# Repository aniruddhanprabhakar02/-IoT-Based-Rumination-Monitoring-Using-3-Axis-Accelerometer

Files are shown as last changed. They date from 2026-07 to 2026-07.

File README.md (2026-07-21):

# IoT-Based Cattle Rumination Monitoring and Health Analysis System










<p align="center">
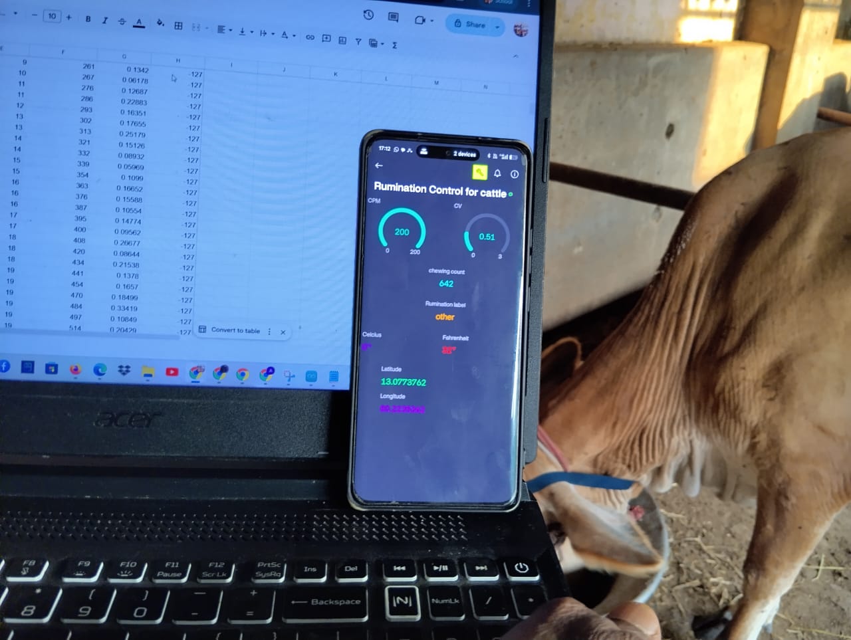
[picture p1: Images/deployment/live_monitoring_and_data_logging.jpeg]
IoT-Based Cattle Rumination Monitoring System
  
</p>

## Project Overview

This project presents an IoT-based cattle monitoring system designed to monitor rumination behavior, body temperature, and cattle location in real time.

The system uses an **ESP32-WROOM-32** microcontroller integrated with an **MPU6050 accelerometer**, **DS18B20 temperature sensor**, and **NEO-6M GPS module**. Accelerometer signals are processed using digital signal processing techniques to estimate chewing activity and classify rumination behavior. The processed data is visualized through a **Blynk IoT dashboard** and logged to **Google Sheets** for long-term monitoring and analysis.

### Applications

- Livestock Health Monitoring
- Precision Livestock Farming
- Behavioral Analytics
- Early Disease Detection
- Heat Stress Monitoring

---

# Key Features

- Real-time rumination monitoring
- Jaw movement sensing using MPU6050
- Signal filtering and peak detection
- Chews Per Minute (CPM) estimation
- Coefficient of Variation (CV) analysis
- Rule-based rumination classification
- Temperature monitoring using DS18B20
- GPS-based cattle tracking
- Blynk IoT dashboard integration
- Google Sheets cloud logging
- Custom PCB design using KiCad
- Field-tested on live cattle

---

# System Workflow

<p align="center">
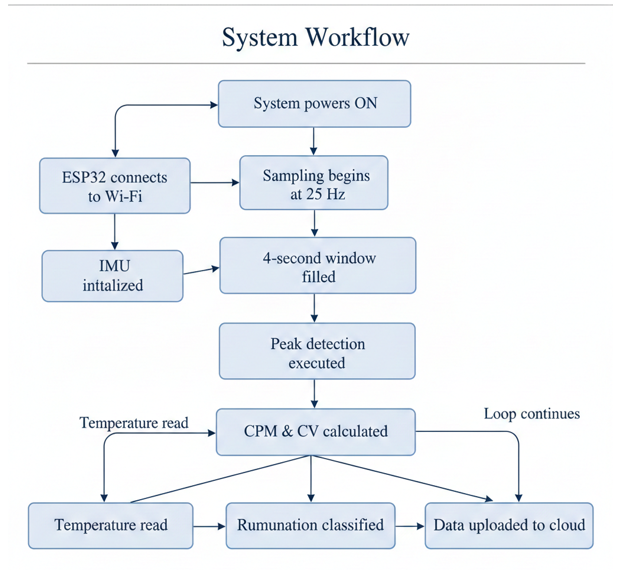
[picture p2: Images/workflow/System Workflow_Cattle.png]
  
</p>

The firmware continuously acquires accelerometer data, applies digital filtering, detects chewing events, computes behavioral metrics (CPM and CV), classifies rumination activity, and uploads the processed information to cloud platforms for visualization and storage.

---

# Hardware Components

| Component | Purpose |
|---|---|
| ESP32-WROOM-32 | Main Controller |
| MPU6050 | Jaw Motion Detection |
| DS18B20 | Temperature Monitoring |
| NEO-6M GPS | Location Tracking |
| 18650 Battery | Portable Power Supply |
| Perfboard Prototype | Hardware Integration |

---

# Hardware Prototype

<p align="center">
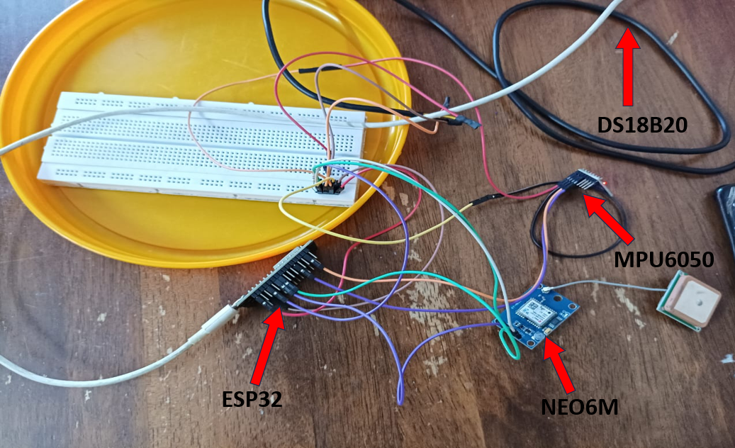
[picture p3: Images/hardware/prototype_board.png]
  
</p>

The prototype integrates:

- ESP32-WROOM-32
- MPU6050 Accelerometer
- DS18B20 Temperature Sensor
- NEO-6M GPS Module
- Battery Power Supply

---

# IoT Dashboard

<p align="center">
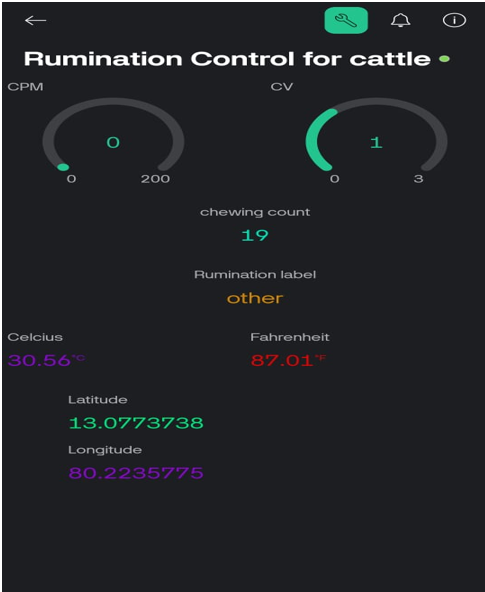
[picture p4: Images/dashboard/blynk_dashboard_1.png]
  
</p>

The Blynk dashboard provides real-time visualization of:

- Chews Per Minute (CPM)
- Coefficient of Variation (CV)
- Rumination Status
- Temperature
- Total Chew Count
- GPS Location

---

# Results Summary

The developed system successfully demonstrated:

- Real-time chewing detection
- Rumination behavior classification
- Continuous temperature monitoring
- GPS-based cattle tracking
- Cloud data logging using Google Sheets
- Real-time dashboard visualization
- Successful deployment on live cattle

---

# Repository Structure

```text
ESP32-Cattle-Rumination-Monitoring
│
├── README.md
│
├── docs
│   ├── Methodology.md
│   ├── PCB_Design.md
│   ├── Results.md
│   ├── References.md
│   └── papers/
│       ├── paper_1.pdf
│       ├── paper_2.pdf
│       └── paper_3.pdf
│
├── firmware
│   └── rumination_monitoring.ino
│
├── hardware
│   ├── schematic/
│   ├── pcb_layout/
│   └── gerber_files/
│
├── images
│   ├── hardware/
│   ├── deployment/
│   ├── dashboard/
│   ├── workflow/
│   └── pcb/
│
├── videos/
│
├── data/
│
└── LICENSE
```

---

# Documentation

Detailed project documentation is available below:

- 📖 [Methodology](Docs/Methodology.md)
- 🔧 [PCB Design Report](Docs/PCB_Design.md)
- 📊 [Experimental Results](Docs/Results.md)
- 📚 [Research References](Docs/References.md)

---

# Technologies Used

### Hardware

- ESP32-WROOM-32
- MPU6050
- DS18B20
- NEO-6M GPS

### Software

- Arduino IDE
- KiCad
- Blynk IoT
- Google Sheets

### Concepts

- Embedded Systems
- Internet of Things (IoT)
- Digital Signal Processing
- Peak Detection
- Statistical Feature Extraction
- Cloud Telemetry
- PCB Design

---

# Future Enhancements

- Machine Learning-Based Rumination Detection
- Health Anomaly Detection
- Heat Stress Prediction
- LoRa-Based Long-Range Communication
- Solar-Powered Sensor Node
- Custom PCB Fabrication and Miniaturization

---

# Author

**Aniruddhan P**

*M.E. Embedded Systems and Technologies*

**Embedded Systems | Embedded Linux | IoT | Edge AI**

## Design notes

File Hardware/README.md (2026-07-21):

# Hardware Design Files

This directory contains the KiCad design files for the custom PCB developed for the IoT-Based Cattle Rumination Monitoring System.

## Project Files

| File | Description |
|---|---|
| `rumination.kicad_pro` | KiCad project file |
| `rumination.kicad_sch` | Schematic design |
| `rumination.kicad_pcb` | PCB layout |

## Gerber Files

The `gerber_files/` directory contains the fabrication-ready Gerber files generated from KiCad.

> **Note:** The PCB was designed as a fabrication-ready prototype. The experimental validation presented in this repository was performed using a perfboard-based hardware prototype rather than the fabricated PCB.

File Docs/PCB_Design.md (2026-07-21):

# PCB Design Using KiCad

## Overview

To improve hardware integration and gain practical PCB design experience, a custom PCB was designed for the ESP32-based cattle rumination monitoring system using **KiCad**.

The design integrates:

- ESP32-WROOM-32
- MPU6050 Accelerometer
- DS18B20 Temperature Sensor
- NEO-6M GPS Module

> **Note:** The deployed cattle monitoring system was implemented using a perfboard prototype. The PCB presented here was developed as a fabrication-ready prototype design and was **not manufactured**.

---

# Schematic Design

The schematic was developed based on the firmware architecture and peripheral interface requirements.

## Hardware Interfaces

| Module | Interface | ESP32 Pins |
|---|---|---|
| MPU6050 | I²C | GPIO21 (SDA), GPIO22 (SCL) |
| DS18B20 | One-Wire | GPIO2 |
| NEO-6M GPS | UART | GPIO16 (RX), GPIO17 (TX) |

<p align="center">
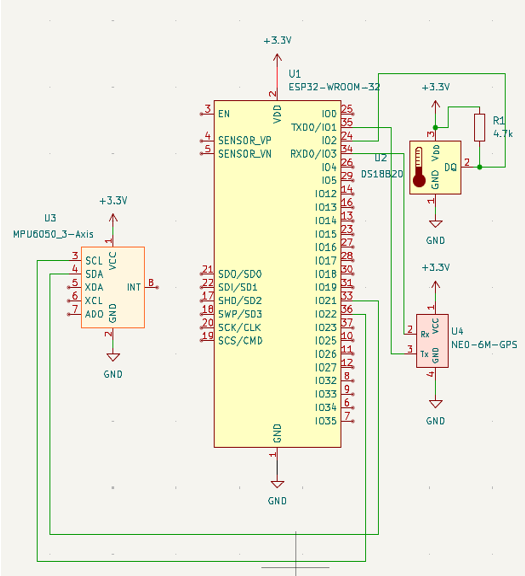
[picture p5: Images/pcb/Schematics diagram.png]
  
</p>

The schematic defines the electrical connectivity between the ESP32 and peripheral modules while ensuring reliable communication through I²C, UART, and One-Wire interfaces.

---

# PCB Layout

The PCB layout was designed with emphasis on compact routing, signal integrity, and ease of hardware integration.

## PCB Specifications

| Parameter | Value |
|---|---|
| PCB Length | 55 mm |
| PCB Width | 85 mm |
| Design Software | KiCad |

## Design Considerations

- Central placement of the ESP32 for simplified routing
- Short I²C traces between ESP32 and MPU6050
- Dedicated ground plane for noise reduction
- GPS antenna clearance
- ESP32 antenna keep-out region

<p align="center">
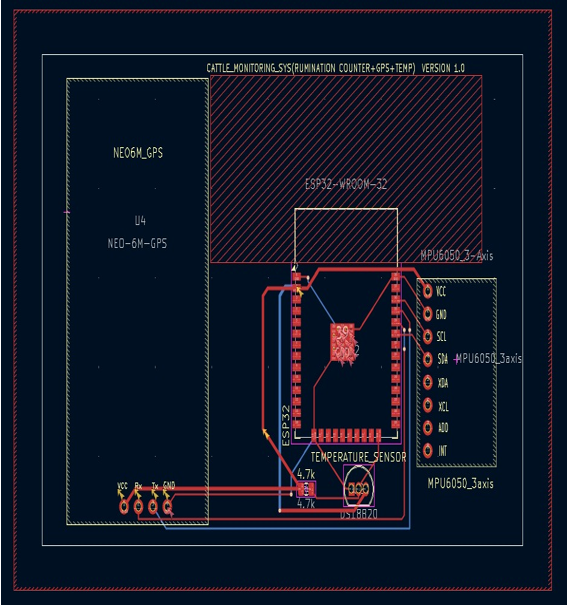
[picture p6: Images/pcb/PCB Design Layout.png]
  
</p>

### PCB Dimensions

<table align="center">
<tr>
<td align="center">

**Length (55 mm)**

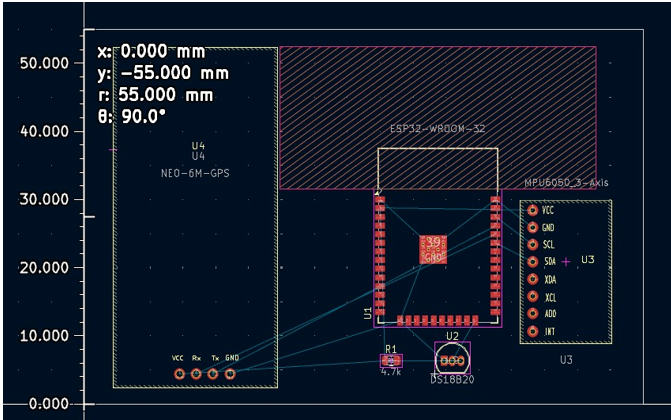
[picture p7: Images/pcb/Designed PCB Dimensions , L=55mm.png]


</td>

<td align="center">

**Width (85 mm)**

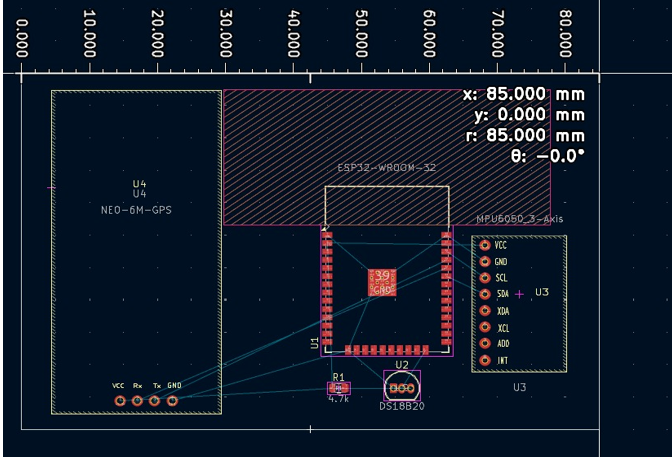
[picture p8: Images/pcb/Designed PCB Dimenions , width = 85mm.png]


</td>
</tr>
</table>

---

# Custom Library Development

Since standard KiCad libraries did not include all required modules, custom symbols and footprints were created using component datasheets.

## Custom Symbols

### MPU6050 Symbol

<p align="center">
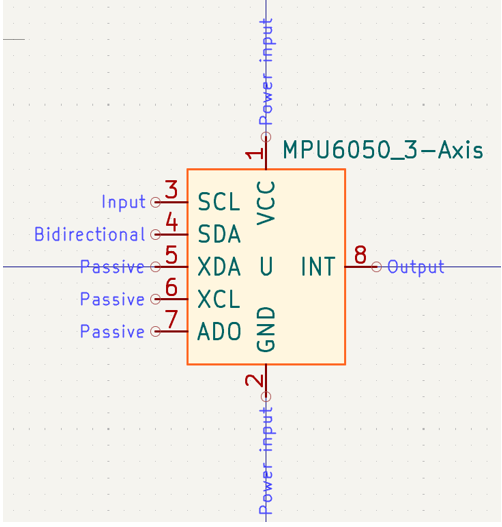
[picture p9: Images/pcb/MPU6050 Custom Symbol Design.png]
  
</p>

### NEO-6M GPS Symbol

<p align="center">
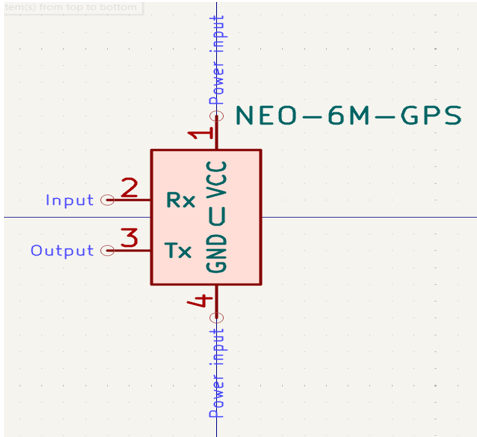
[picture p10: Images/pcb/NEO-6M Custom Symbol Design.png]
  
</p>

The custom symbols accurately define device pin assignments for schematic capture.

---

## Custom Footprints

### MPU6050 Footprint

<p align="center">
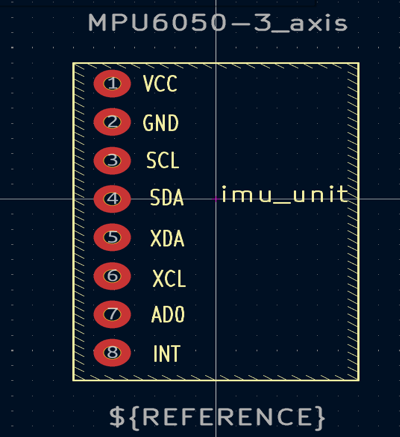
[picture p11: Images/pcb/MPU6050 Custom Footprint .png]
  
</p>

### NEO-6M GPS Footprint

<p align="center">
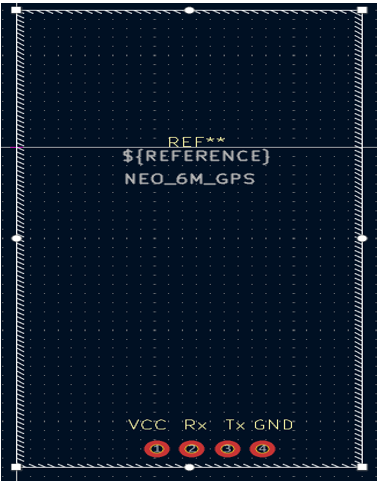
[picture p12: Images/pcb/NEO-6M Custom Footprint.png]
  
</p>

The footprints were created using the physical package dimensions provided in the respective component datasheets to ensure correct PCB placement.

---

# Design Outcomes

The following PCB design activities were successfully completed:

- Schematic Capture
- Custom Symbol Development
- Custom Footprint Development
- PCB Layout Design
- Component Placement
- Signal Trace Routing
- Ground Plane Implementation
- ESP32 Antenna Keep-Out Planning
- Design Rule Verification
- Gerber File Generation

---

# Tools and Components

## Software

- KiCad

## Hardware Components

- ESP32-WROOM-32
- MPU6050 Accelerometer
- DS18B20 Temperature Sensor
- NEO-6M GPS Module

---

# Future Work

- PCB Fabrication
- Component Assembly
- Hardware Validation
- Power Optimization
- Miniaturized Wearable Enclosure

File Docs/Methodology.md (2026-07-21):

# Methodology

## Project Title

**IoT-Based Cattle Rumination Monitoring and Health Analysis System**

---

# 1. Introduction

Rumination behavior is a key indicator of cattle health, digestive efficiency, and overall well-being. Changes in rumination patterns can provide early indications of stress, illness, reduced feed intake, and metabolic disorders.

This project implements an IoT-based rumination monitoring system using an ESP32 microcontroller, inertial sensing, temperature monitoring, and cloud connectivity. Jaw movement data is acquired using an accelerometer, processed using digital signal processing techniques, and analyzed to identify rumination behavior in real time.

---

# 2. System Overview

The developed system performs the following functions:

- Jaw movement sensing using an MPU6050 accelerometer
- Signal conditioning through digital filtering
- Chewing event detection using peak analysis
- Chews Per Minute (CPM) estimation
- Coefficient of Variation (CV) computation
- Rumination classification
- Body temperature monitoring
- GPS-based location tracking
- Cloud-based visualization and logging

---

# 3. Hardware Architecture

## 3.1 ESP32 Microcontroller

The ESP32 serves as the central processing unit of the system.

### Responsibilities

- Sensor data acquisition
- Signal processing
- Feature extraction
- Rumination classification
- Wi-Fi communication
- Cloud data transmission

### Features

- Built-in Wi-Fi
- Dual-core architecture
- Multiple GPIO interfaces
- I²C and UART support
- Low power consumption

---

## 3.2 MPU6050 Accelerometer

The MPU6050 is used to capture jaw movement associated with chewing activity.

### Configuration

| Parameter | Value |
|---|---|
| Accelerometer Range | ±8 g |
| Sampling Frequency | 25 Hz |
| Interface | I²C |
| I²C Address | 0x68 |

### Acceleration Magnitude

To reduce sensitivity to sensor orientation, acceleration magnitude is calculated using:

```math
|a| = \sqrt{a_x^2 + a_y^2 + a_z^2}
```

Where:

- ax = Acceleration along X-axis
- ay = Acceleration along Y-axis
- az = Acceleration along Z-axis

The magnitude signal is used for subsequent processing.

---

## 3.3 DS18B20 Temperature Sensor

The DS18B20 sensor measures cattle body temperature.

### Features

- Digital output
- One-Wire communication
- High measurement accuracy
- Low power consumption

Temperature data is transmitted alongside rumination information for health monitoring.

---

## 3.4 NEO-6M GPS Module

The GPS module provides real-time location tracking.

### Information Captured

- Latitude
- Longitude

Location information can be used for animal tracking and grazing behavior analysis.

---

# 4. Data Acquisition

Accelerometer data is continuously sampled at:

```text
Sampling Frequency = 25 Hz
```

### Analysis Window

```text
Window Duration = 4 Seconds
```

### Samples Per Window

```text
N = FS × Window Duration

N = 25 × 4

N = 100 Samples
```

For each sample:

1. Read accelerometer values
2. Compute acceleration magnitude
3. Apply filtering
4. Store filtered value in buffer
5. Analyze when the window is complete

---

# 5. Signal Processing

Raw accelerometer measurements contain:

- Gravity components
- Body movement artifacts
- Environmental disturbances
- Sensor noise

To isolate jaw movement associated with rumination, a two-stage filtering process is used.

---

## 5.1 High-Pass Filter

The high-pass filter removes low-frequency body movement and gravity effects.

### Equation

```math
y[n] = \alpha \left( y[n-1] + x[n] - x[n-1] \right)
```

Where:

```text
α = 0.88
```

### Purpose

- Remove slow body motion
- Remove posture changes
- Suppress gravity effects

---

## 5.2 Low-Pass Filter

The low-pass filter removes high-frequency noise.

### Equation

```math
y[n] = y[n-1] + \beta \left( x[n] - y[n-1] \right)
```

Where:

```text
β = 0.70
```

### Purpose

- Reduce sensor noise
- Smooth signal fluctuations
- Preserve chewing-related motion

---

## 5.3 Band-Limited Chewing Signal

The combined filtering stages produce a signal dominated by chewing activity while suppressing unwanted motion and noise.

```text
Acceleration Magnitude
        │
        ▼
High-Pass Filter
        │
        ▼
Low-Pass Filter
        │
        ▼
Filtered Signal
```

---

# 6. Peak Detection

Chewing activity produces periodic peaks in the filtered signal.

A chewing event is detected when:

```text
x[i] > x[i-1]
x[i] > x[i+1]
x[i] > 0.03
```

Each valid peak corresponds to a chewing cycle.

### Measurements Recorded

- Peak count
- Peak amplitude
- Peak intervals
- Total chew count

---

# 7. Feature Extraction

Two primary features are extracted from every analysis window.

---

## 7.1 Chews Per Minute (CPM)

CPM represents chewing frequency.

### Calculation

```math
CPM =
\frac{\text{Number of Peaks}}
{\text{Window Duration (Minutes)}}
```

### Interpretation

| CPM Value | Interpretation |
|---|---|
| Low | Minimal chewing activity |
| Moderate | Possible rumination |
| High | Active chewing behavior |

---

## 7.2 Coefficient of Variation (CV)

CV measures the regularity of chewing intervals.

### Calculation

```math
CV = \frac{\sigma}{\mu}
```

Where:

- σ = Standard deviation of peak intervals
- μ = Mean peak interval

### Interpretation

| CV Value | Interpretation |
|---|---|
| Low | Rhythmic chewing |
| High | Irregular movement |

---

# 8. Rumination Classification

Rumination is identified using frequency and rhythmic consistency.

A window is classified as rumination when:

```text
30 ≤ CPM ≤ 140
```

AND

```text
CV < 1.35
```

If both conditions are satisfied:

```text
Label = Rumination
```

Otherwise:

```text
Label = Other Activity
```

---

# 9. Temperature Monitoring

At the end of each analysis window:

1. Read DS18B20 temperature
2. Convert to Celsius
3. Convert to Fahrenheit
4. Upload to cloud platform

Temperature measurements are correlated with rumination activity for health assessment.

---

# 10. Cloud Data Transmission

Data is transmitted using Wi-Fi connectivity provided by the ESP32.

## Blynk Dashboard

The following parameters are visualized:

- CPM
- CV
- Rumination Status
- Total Chew Count
- Temperature
- GPS Data

---

## Google Sheets Logging

Data is uploaded using HTTP POST requests.

### Logged Parameters

- CPM
- CV
- Rumination Label
- Rumination Count
- Total Chews
- Peak Amplitude
- Temperature

This enables long-term behavioral analysis and record keeping.

---

# 11. System Workflow

The following workflow illustrates the complete data acquisition, signal processing, rumination classification, and cloud communication pipeline implemented in the developed system.

<p align="center">
  System Workflow
</p>

### Workflow Description

1. The ESP32 initializes the sensors and establishes a Wi-Fi connection.
2. The MPU6050 continuously acquires jaw movement acceleration data at 25 Hz.
3. The acceleration magnitude is computed from the three-axis measurements.
4. High-pass and low-pass digital filters remove unwanted motion artifacts and sensor noise.
5. The filtered signal is stored in a 4-second analysis window.
6. Peak detection identifies individual chewing events.
7. Chews Per Minute (CPM) and Coefficient of Variation (CV) are computed.
8. Rumination behavior is classified using the predefined CPM and CV thresholds.
9. Body temperature is measured using the DS18B20 sensor.
10. GPS coordinates are acquired from the NEO-6M module.
11. All processed information is transmitted to the Blynk dashboard and logged to Google Sheets for remote monitoring and long-term analysis.

### Processing Pipeline

```text
System Power ON
       │
       ▼
Connect to Wi-Fi
       │
       ▼
Initialize Sensors
       │
       ▼
Acquire IMU Data
       │
       ▼
Compute Magnitude
       │
       ▼
High-Pass Filtering
       │
       ▼
Low-Pass Filtering
       │
       ▼
Fill Analysis Window
       │
       ▼
Peak Detection
       │
       ▼
Compute CPM & CV
       │
       ▼
Rumination Classification
       │
       ▼
Read Temperature
       │
       ▼
Read GPS Data
       │
       ▼
Upload to Cloud
       │
       ▼
Repeat
```

# 12. System Innovations

Compared to basic threshold-counting approaches, the proposed system introduces:

- Acceleration magnitude-based analysis
- Two-stage digital filtering
- Statistical CV-based rhythm validation
- Combined frequency and regularity classification
- Cloud-based telemetry and logging
- Integrated temperature monitoring
- Real-time dashboard visualization

---

# 13. Outcome

The developed system successfully:

- Detected chewing events in real time
- Estimated chewing frequency
- Measured chewing regularity
- Classified rumination behavior
- Monitored body temperature
- Logged cloud telemetry
- Visualized data remotely through Blynk

The architecture provides a foundation for future livestock health monitoring applications, including:

- Early disease detection
- Heat stress monitoring
- Automated alert generation
- Machine learning-based health prediction
- Precision livestock farming

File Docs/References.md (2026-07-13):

# References

The design of the rumination monitoring algorithm, sensor placement strategy, and behavioral analysis methodology was inspired by prior research on accelerometer-based livestock monitoring systems.

---

## Research Papers

### [1] Iqbal et al., 2021

**Validation of an Accelerometer Sensor-Based Collar for Monitoring Grazing and Rumination Behaviours in Dairy Cows**

Key Contributions:

- Accelerometer-based rumination monitoring
- Chewing activity analysis
- Behavioral classification using motion data
- Validation of wearable sensing approaches

Influenced:

- CPM (Chews Per Minute) analysis
- Rumination detection methodology
- Wearable sensor deployment strategy

---

### [2] Riaboff et al., 2020

**Monitoring Pasture-Based Dairy Cow Behaviour Using Accelerometer-Based Sensors**

Key Contributions:

- Activity recognition using inertial sensors
- Grazing and rumination behavior analysis
- Sensor placement considerations

Influenced:

- Accelerometer placement methodology
- Motion signal interpretation
- Livestock behavior monitoring concepts

---

### [3] Mauny et al., 2019

**Automatic Classification of Rumination and Ingestive Behaviors in Cattle Using Machine Learning Techniques**

## Supporting Literature

The research papers referenced during development are available in:

docs/papers/

Key Contributions:

- Rumination classification approaches
- Behavioral feature extraction
- Automated livestock monitoring

Influenced:

- Feature engineering concepts
- Rumination classification framework
- Future machine learning enhancements

---

## Technical References

### ESP32 Documentation

- ESP32-WROOM-32 Technical Reference Manual
- ESP32 Datasheet
- Espressif Systems Documentation

Used For:

- GPIO configuration
- Wi-Fi communication
- Peripheral interfacing

---

### MPU6050 Documentation

- MPU6050 Product Specification
- MPU6050 Register Map Documentation

Used For:

- Accelerometer configuration
- Motion sensing implementation
- Sampling rate configuration

---

### DS18B20 Documentation

- DS18B20 Digital Temperature Sensor Datasheet

Used For:

- One-Wire communication
- Temperature acquisition

---

### NEO-6M Documentation

- u-blox NEO-6M GPS Module Documentation

Used For:

- GPS interfacing
- Location acquisition

---

### KiCad Documentation

- KiCad Official Documentation

Used For:

- Schematic capture
- PCB layout design
- Custom symbol creation
- Custom footprint development

---

## Software Libraries

### Arduino Framework

Used for:

- ESP32 firmware development
- Peripheral integration
- Real-time data acquisition

### Blynk IoT Platform

Used for:

- Cloud connectivity
- Dashboard visualization
- Remote monitoring

### Google Sheets Web App

Used for:

- Cloud-based data logging
- Long-term data storage

---

## Disclaimer

This project implements a lightweight rule-based rumination detection approach optimized for real-time execution on ESP32 hardware. The methodology was inspired by published research on livestock behavior monitoring but was independently implemented, tuned, and experimentally validated as part of this project.

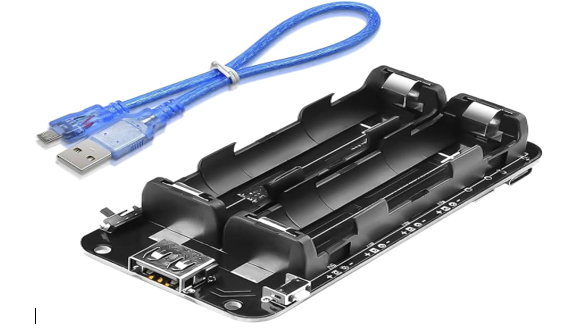
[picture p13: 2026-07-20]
Images/hardware/18650 Battery Holder .png

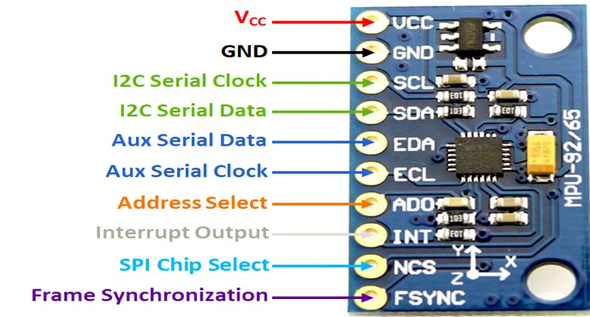
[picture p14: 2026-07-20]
Images/hardware/MPU6050_sensor.png

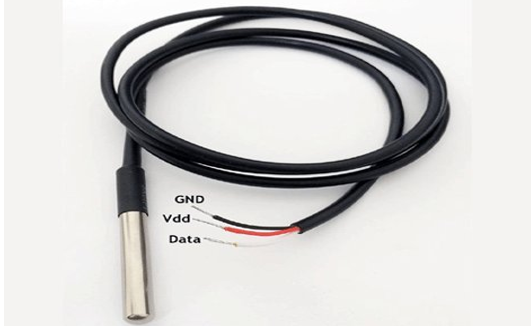
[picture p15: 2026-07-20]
Images/hardware/DS18B20_sensor.png

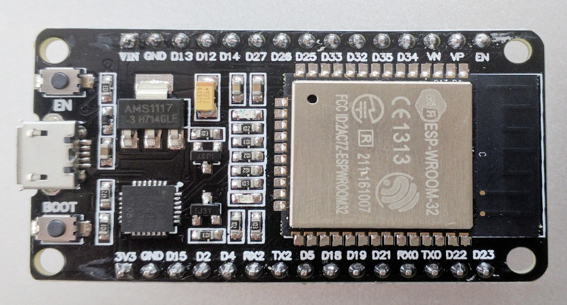
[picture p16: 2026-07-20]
Images/hardware/esp32_MC.png

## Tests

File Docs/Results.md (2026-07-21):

# Experimental Results

## Overview

The developed IoT-based cattle monitoring system was experimentally evaluated under real-world farm conditions. The system successfully acquired jaw movement data, estimated chewing activity, classified rumination behavior, monitored body temperature, and transmitted data to cloud platforms for real-time visualization and long-term logging.

---

# Hardware Prototype

The complete system was implemented using a **perfboard-based hardware prototype** integrating the ESP32-WROOM-32, MPU6050 accelerometer, DS18B20 temperature sensor, and NEO-6M GPS module.

<p align="center">
  
</p>

### Prototype Features

- ESP32-based embedded controller
- Wireless Wi-Fi connectivity
- MPU6050 jaw motion sensing
- DS18B20 temperature monitoring
- GPS-based cattle tracking
- Battery-powered portable operation

---

# Field Deployment

The developed system was deployed on live cattle to evaluate rumination monitoring under actual farm conditions.

<p align="center">
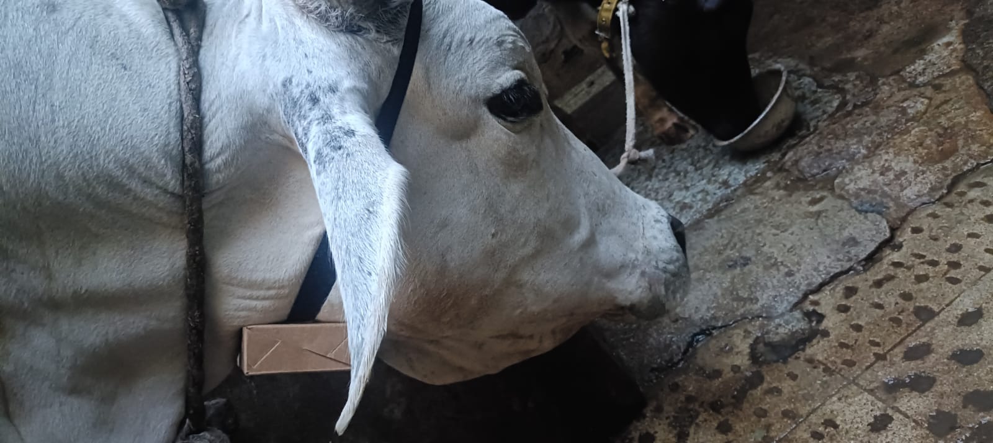
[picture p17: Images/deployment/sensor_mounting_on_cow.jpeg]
  
</p>

### Sensor Placement

The sensing unit was securely mounted near the mandibular (jaw) region to capture chewing-induced movements while minimizing interference from general body motion.

---

## Live Monitoring and Data Logging

The complete monitoring system was validated by simultaneously observing cattle behavior, the Blynk dashboard, and cloud-based data logging.

<p align="center">
  
</p>

### Experimental Validation

The deployment verified:

- Real-time jaw movement acquisition
- Continuous rumination monitoring
- Wireless data transmission
- Cloud-based data logging
- End-to-end system operation under field conditions

---

# Blynk Dashboard Visualization

The processed sensor data was transmitted to the Blynk IoT platform for remote monitoring and visualization.

<p align="center">
  
</p>

### Dashboard Parameters

The dashboard displays:

- Chews Per Minute (CPM)
- Coefficient of Variation (CV)
- Rumination Status
- Total Chew Count
- Body Temperature
- GPS Location

---

# Experimental Observations

The experimental evaluation demonstrated that the developed system successfully:

- Acquired continuous accelerometer data from jaw movements
- Performed real-time digital signal processing on the ESP32
- Detected chewing events using peak detection
- Estimated chewing frequency (CPM)
- Evaluated chewing regularity using CV
- Classified rumination behavior using embedded firmware
- Monitored body temperature
- Uploaded sensor data to cloud platforms
- Visualized animal activity using the Blynk dashboard
- Successfully operated during live cattle deployment

---

# System Validation

The project validates the integration of embedded sensing, digital signal processing, and IoT technologies for livestock health monitoring.

## Embedded System Validation

- ESP32 firmware implementation
- Multi-sensor integration
- Real-time signal processing
- Embedded rumination classification

## IoT Validation

- Wi-Fi communication
- Cloud telemetry
- Remote dashboard visualization
- Long-term data logging

## Livestock Monitoring Validation

- Jaw movement sensing
- Rumination behavior analysis
- Temperature monitoring
- GPS-based location tracking

---

# Limitations

Current limitations of the prototype include:

- Rule-based rumination classification using fixed thresholds
- GPS accuracy dependent on satellite availability
- Battery life optimization not extensively evaluated
- PCB designed but not fabricated or experimentally validated

---

# Future Improvements

Potential enhancements include:

- Machine Learning-based rumination classification
- Automated health anomaly detection
- Heat stress prediction
- LoRa-based long-range communication
- Solar-powered sensor node
- Fabrication and validation of the custom PCB
- Mobile notification and alert system

---

# Demonstration Media

Additional demonstrations of the project are available in the repository:

```text
/videos/
```

Including:

- Hardware Demonstration
- Live Cattle Deployment
- Dashboard Monitoring
- Cloud Data Logging

---

# Conclusion

The developed IoT-based cattle rumination monitoring system successfully demonstrated real-time jaw movement sensing, rumination classification, temperature monitoring, cloud connectivity, and remote visualization. The successful field deployment validates the feasibility of using low-cost embedded sensing and digital signal processing techniques for precision livestock health monitoring.

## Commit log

2026-07-13 adding results and pcb design md file
2026-07-20 updated img loc in methodology,pcb_design and results
2026-07-20 Update Methodology.md system flow image
2026-07-20 Fix image paths in PCB_Design.md
    Updated image paths in PCB design documentation to use relative paths.
2026-07-21 added kicad files
    [rumination-B_Mask.gbs, rumination-B_Paste.gbp, rumination-B_Silkscreen.gbo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]

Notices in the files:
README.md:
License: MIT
